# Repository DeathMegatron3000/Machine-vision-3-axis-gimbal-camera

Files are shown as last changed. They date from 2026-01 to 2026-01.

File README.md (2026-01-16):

# This project is still WIP, a full guide will be out when im finished with it
# 3-Axis AI Tracking Gimbal

A high-performance active stabilizing gimbal using **Computer Vision (YOLOv8)** on a **Raspberry Pi 5** for object tracking, and an **ESP32** for real-time motor control and IMU stabilization.

## Features
- **Object Tracking:** Uses YOLOv8 (Nano) to track people/objects at high framerates.
- **Hybrid Motor Control:** 
  - **Pan:** NEMA 17 Stepper (via TMC2209) for 360° continuous rotation.
  - **Tilt:** MG90S metal micro servo motor 
  - **Roll:** ES08MDII digital metal micro servo motor
- **Auto-Leveling:** MPU6500 IMU keeps the camera horizon level (Roll axis) independently of tracking.
- **Communication:** UART Serial link between Pi 5 (Vision) and ESP32 (Motion).

## 🛠 Hardware List
- **Compute:** Raspberry Pi 5 (8GB) + Camera Module 3
- **Controller:** ESP32 Dev Module
- **Motors:** 
  - Pan: NEMA 17 Stepper
  - Tilt: MG90s Metal Gear Servo
  - Roll: ES08MDII Metal Gear Servo
- **Drivers & Sensors:** 
  - TMC2209 Stepper Driver (UART/DIR mode)
  - MPU6500 6-Axis Gyro/Accelerometer
- **Power:** External 12V (Stepper) and 5V (Pi/Servos) sources

## Wiring Overview
| Component | Pin | Connected To |
|---|-----|---|
| **Pi 5**  | UART TX (GPIO14)| ESP32 RX (GPIO16/User Def) |
| **Pi 5**  | UART RX (GPIO15)| ESP32 TX (GPIO17/User Def) |
| **Stepper**| STEP | ESP32 GPIO 25 |
| **Stepper**| DIR | ESP32 GPIO 26 |
| **Servo** | Tilt Signal | ESP32 GPIO 17 |
| **Servo** | Roll Signal | ESP32 GPIO 16 |
| **IMU** | SDA/SCL | ESP32 GPIO 21/22 |

## 💻 Installation

### 1. Raspberry Pi (Vision)
```bash
cd rpi_vision
pip install -r requirements.txt
python main.py

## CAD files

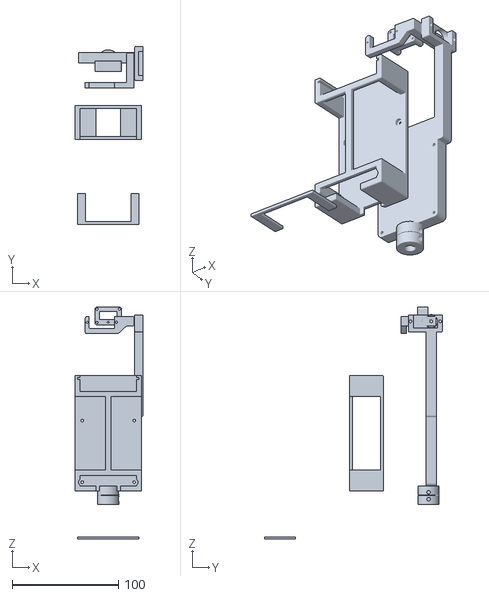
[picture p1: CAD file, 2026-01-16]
new 3a.stl
64.5 x 167.6 x 218.5

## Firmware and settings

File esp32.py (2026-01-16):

/**
 * 3-Axis AI Gimbal Controller
 * Platform: ESP32
 * Motors: NEMA 17 (Pan), MG90S (Tilt), ES08MDII (Roll)
 * Sensor: MPU6500/MPU9250
 */

#include <Wire.h>
#include <MPU9250_WE.h>
#include <ESP32Servo.h>
#include <AccelStepper.h>

// --- PIN DEFINITIONS ---
#define I2C_SDA_PIN 21
#define I2C_SCL_PIN 22
#define MPU_ADDR 0x68

#define PAN_STEP_PIN 25
#define PAN_DIR_PIN 26
#define TILT_SERVO_PIN 17
#define ROLL_SERVO_PIN 16

// --- TUNING PARAMETERS ---
// Roll Stabilization (PID-ish)
const float ROLL_KP = 1.3;        // Proportional gain for Roll
const float ROLL_OFFSET = 90.0;   // Mechanical center of the servo

// Vision Tracking Gains
// Adjust these if tracking is too slow (increase) or oscillates (decrease)
const float PAN_GAIN = 0.25;      // Stepper steps per pixel error
const float TILT_GAIN = 0.08;     // Servo degrees per pixel error

// --- OBJECTS ---
MPU9250_WE myMPU = MPU9250_WE(MPU_ADDR);
Servo RollServo;
Servo TiltServo;
// Interface 1 = Driver (STEP + DIR)
AccelStepper panStepper(AccelStepper::DRIVER, PAN_STEP_PIN, PAN_DIR_PIN);

// --- VARIABLES ---
float fusedRoll = 0.0;
unsigned long lastImuTime = 0;
float currentTiltAngle = 90.0;    // Start Tilt at middle

// Serial Parsing
String inputString = "";
bool stringComplete = false;

void setup() {
  Serial.begin(115200);
  Wire.begin();

  // 1. Setup IMU
  if (!myMPU.init()) {
    Serial.println("IMU Connection Failed!");
  } else {
    Serial.println("IMU Connected.");
  }
  
  Serial.println("Calibrating IMU (Keep flat)...");
  delay(1000);
  myMPU.autoOffsets();
  
  // IMU Filters
  myMPU.setSampleRateDivider(5);
  myMPU.setAccRange(MPU9250_ACC_RANGE_2G);
  myMPU.enableAccDLPF(true);
  myMPU.setAccDLPF(MPU9250_DLPF_6);

  // 2. Setup Servos
  RollServo.attach(ROLL_SERVO_PIN);
  TiltServo.attach(TILT_SERVO_PIN);
  RollServo.write(ROLL_OFFSET);
  TiltServo.write(currentTiltAngle);

  // 3. Setup Stepper
  // Adjust MaxSpeed based on microstepping (e.g., 1/16 needs higher values)
  panStepper.setMaxSpeed(3000);
  panStepper.setAcceleration(2000);
  panStepper.setMinPulseWidth(20); 

  Serial.println("GIMBAL INITIALIZED");
}

void loop() {
  // --- CRITICAL: STEPPER MOTION ---
  // This must be called as fast as possible in the loop.
  // Do not use delay() inside loop()!
  panStepper.run();

  // --- IMU STABILIZATION (ROLL) ---
  // Run this approx every 10ms (100Hz)
  unsigned long currentTime = millis();
  if ((currentTime - lastImuTime) >= 10) {
    float dt = (currentTime - lastImuTime) / 1000.0;
    lastImuTime = currentTime;

    // Read Sensor
    xyzFloat gyr = myMPU.getGyrValues();
    float accRoll = myMPU.getPitch(); // NOTE: Check if getPitch or getRoll suits your mount
    
    // Complementary Filter
    fusedRoll = 0.98 * (fusedRoll + gyr.y * dt) + 0.02 * accRoll;

    // Calculate Correction (Target = 0 degrees flat)
    float error = 0 - fusedRoll;
    float correction = ROLL_KP * error;
    
    // Write to Servo
    float servoPos = ROLL_OFFSET + correction;
    servoPos = constrain(servoPos, 0, 180);
    RollServo.write(servoPos);
  }

  // --- SERIAL COMMUNICATION ---
  // Read incoming data from Raspberry Pi
  while (Serial.available()) {
    char inChar = (char)Serial.read();
    if (inChar == '\n') {
      stringComplete = true;
    } else {
      inputString += inChar;
    }
  }

  // Parse Command
  if (stringComplete) {
    parseVisionData();
    inputString = "";
    stringComplete = false;
  }
}

void parseVisionData() {
  // Expected Format: "P<pan_error>T<tilt_error>"
  // Example: "P-40T20"
  
  int pIndex = inputString.indexOf('P');
  int tIndex = inputString.indexOf('T');

  if (pIndex != -1 && tIndex != -1) {
    String pStr = inputString.substring(pIndex + 1, tIndex);
    String tStr = inputString.substring(tIndex + 1);

    int panError = pStr.toInt();
    int tiltError = tStr.toInt();

    // 1. Update Pan (Stepper)
    // Relative movement based on error
    if (panError != 0) {
      long targetPos = panStepper.currentPosition() + (panError * PAN_GAIN);
      panStepper.moveTo(targetPos);
    }

    // 2. Update Tilt (Servo)
    if (tiltError != 0) {
      // Invert +/- if tilt moves wrong way
      currentTiltAngle += (tiltError * TILT_GAIN);
      currentTiltAngle = constrain(currentTiltAngle, 10, 170); // Safety limits
      TiltServo.write(currentTiltAngle);
    }
  }
}

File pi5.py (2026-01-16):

import cv2
from ultralytics import YOLO
import serial
import time
import sys

# configuration
MODEL_NAME = 'yolov8n.pt'      # nano model
CONFIDENCE_THRESHOLD = 0.5     # minimum confidence to track
LOST_TARGET_THRESHOLD = 30     # frames to wait before resetting ID
SERIAL_PORT = '/dev/ttyAMA0'   # UART Pin on Pi 5 (GPIO 14 TX / 15 RX)
BAUD_RATE = 115200
CAMERA_ID = 0                  # 0 is usually the default Camera Module

# serial connect
try:
    ser = serial.Serial(SERIAL_PORT, BAUD_RATE, timeout=1)
    ser.flush()
    print(f"[INFO] Serial connected on {SERIAL_PORT}")
except Exception as e:
    print(f"[WARNING] Serial connection failed: {e}")
    print("[INFO] Running in Vision-Only mode (No motor control)")
    ser = None

# load model
print(f"[INFO] Loading YOLOv8 Model: {MODEL_NAME}...")
model = YOLO(MODEL_NAME)

# camera setup
cap = cv2.VideoCapture(CAMERA_ID)
cap.set(cv2.CAP_PROP_FRAME_WIDTH, 640)
cap.set(cv2.CAP_PROP_FRAME_HEIGHT, 480)

if not cap.isOpened():
    print("[ERROR] Could not open Camera Module 3.")
    sys.exit()

# get frame dim
frame_width = int(cap.get(cv2.CAP_PROP_FRAME_WIDTH))
frame_height = int(cap.get(cv2.CAP_PROP_FRAME_HEIGHT))
frame_center_x = frame_width // 2
frame_center_y = frame_height // 2

# tracking
target_id = None
lost_target_counter = 0

print("[INFO] System Ready. Press 'q' to quit.")

try:
    while True:
        success, frame = cap.read()
        if not success:
            print("[ERROR] Failed to read frame")
            break

        # run yolo
        # persist=True keeps the ID assigned to the same object
        results = model.track(frame, classes=0, conf=CONFIDENCE_THRESHOLD, persist=True, verbose=False)
        
        # manual draw for optimize performance
        annotated_frame = frame 
        
        target_found = False

        # if objects are detected
        if results[0].boxes.id is not None:
            boxes = results[0].boxes.xyxy.cpu().numpy().astype(int)
            ids = results[0].boxes.id.cpu().numpy().astype(int)

            # aquire mode: find a target if none
            if target_id is None:
                min_dist = float('inf')
                best_id = -1
                
                for i, box in enumerate(boxes):
                    # calculate dist from cent
                    cx = (box[0] + box[2]) // 2
                    cy = (box[1] + box[3]) // 2
                    dist = ((cx - frame_center_x)**2 + (cy - frame_center_y)**2)**0.5
                    
                    # draw all in red
                    cv2.rectangle(annotated_frame, (box[0], box[1]), (box[2], box[3]), (0, 0, 255), 2)
                    
                    if dist < min_dist:
                        min_dist = dist
                        best_id = ids[i]
                
                # lock to closest
                if best_id != -1:
                    target_id = best_id
                    lost_target_counter = 0
                    print(f"[TRACKING] Acquired Target ID: {target_id}")

            # tracking mode: follow locked ID
            if target_id is not None:
                for i, box in enumerate(boxes):
                    if ids[i] == target_id:
                        target_found = True
                        lost_target_counter = 0
                        
                        # get target cent
                        cx = (box[0] + box[2]) // 2
                        cy = (box[1] + box[3]) // 2
                        
                        # calculate error (pixel distance from cent)
                        # pan error: x difference
                        # tilt error: y difference
                        pan_error = frame_center_x - cx
                        tilt_error = frame_center_y - cy
                        
                        # draw target in green
                        cv2.rectangle(annotated_frame, (box[0], box[1]), (box[2], box[3]), (0, 255, 0), 2)
                        cv2.circle(annotated_frame, (cx, cy), 5, (0, 255, 0), -1)
                        
                        # send to esp32
                        # Protocol: "P<pan_val>T<tilt_val>\n"
                        # Example: "P-45T120\n"
                        if ser is not None:
                            command = f"P{pan_error}T{tilt_error}\n"
                            ser.write(command.encode('utf-8'))
                        break
        
        # action when lost target
        if target_id is not None and not target_found:
            lost_target_counter += 1
            if lost_target_counter > LOST_TARGET_THRESHOLD:
                print(f"[TRACKING] Target ID {target_id} Lost. Resetting.")
                target_id = None
                lost_target_counter = 0
                # stop motors
                if ser is not None:
                    ser.write(b"P0T0\n")

        # draw crosshair
        cv2.line(annotated_frame, (frame_center_x, frame_center_y - 15), (frame_center_x, frame_center_y + 15), (255, 255, 0), 2)
        cv2.line(annotated_frame, (frame_center_x - 15, frame_center_y), (frame_center_x + 15, frame_center_y), (255, 255, 0), 2)

        # show output
        cv2.imshow("Gimbal Vision", annotated_frame)

        if cv2.waitKey(1) & 0xFF == ord('q'):
            break

except KeyboardInterrupt:
    print("\n[INFO] Stopping...")

finally:
    cap.release()
    cv2.destroyAllWindows()
    if ser is not None:
        ser.close()
